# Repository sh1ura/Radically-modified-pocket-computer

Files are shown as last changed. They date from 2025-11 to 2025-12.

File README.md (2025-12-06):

# ポケコン Linux 化改造

appearances

1988年のポケットコンピュータ（ポケコン） SHARP PC-G801 を改造し、キーボードとディスプレイがついた Linux マシン化しました。

制作過程等は[こちら](https://shiura.com/dfab/sharp-mod/index.html)をごらんください。

### 動画

pockecom (https://youtu.be/T_GSy2BSDts)

## 概要

* Raspberry Pi Zero 2 W を内蔵
  - Linux (Raspberry Pi OS) が動作
  - C や Python など様々な言語でプログラミングが可能
  - WiFi でネットワークに接続でき、apt によるソフト追加・更新、pip による Python パッケージ追加など可能
* ESP32-S3 を内蔵
  - キーボード読み取り、ディスプレイ表示を担当
  - ターミナルは VT100 のサブセットで、emacs 等が使用可能
  - 漢字表示(UTF-8)簡易対応
  - ESP32 単体で起動すると、RPN 関数電卓として動作
* bluetoothキーボード機能を搭載(ESP32)
  - <a href="https://x.com/shiura/status/1997224685965336579">Linux の GUI 画面への文字入力（VNCやHDMIディスプレイの接続時）</a>に利用可能
  - 電卓モードでは<a href="https://x.com/shiura/status/1997232332638740924">計算結果の転送</a>も可能
* 裏面・側面に至るまで、オリジナルの外観をキープ
  - オリジナル同様、単３（ニッケル水素電池）４本で動作
 


### 回路・部品構成

design

 ## 提供物

 * 改造用の PCB （基板）のデータ
 * ESP32 上のコード（VT100サブセットターミナルとRPN関数電卓を統合したもの）
 * ディスプレイを固定するための治具の3Dモデル

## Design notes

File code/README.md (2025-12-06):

# ポケコン改造用 ESP32 コード

ESP32 で以下のことを行うコードです。非常に荒っぽい、汚いコードですのでご了承ください。

### ターミナルモード（Raspberry Pi 起動時）


* UART で Raspberry Pi と通信
  - Bluetoothキーボードとしても動作可能
* 全キーのスキャン（押下状態を取得）
  - 一部については文字コードを生成
  - shift (主に記号入力), caps (大文字入力), ctrl (BASICキー), ESC (カナキー)
* VT100サブセットの ANSI エスケープシーケンス処理
  - 必要最低限のコードのみ処理しています
    - 非対応のコードのため、emacs 等では時々表示がずれることがあります
  - 漢字表示(UTF-8)対応
    - 簡易処理のため、文字欠け等が生じることがあります
    - 表示文字数を減らさないため、漢字は上下に少し文字同士の重なりが生じます
  - カラー・反転等には対応していません
  - 42列7行表示
    - CLS ボタンを押すと `stty rows 7 cols 41; clear` のように画面サイズをセットするコマンドが自動入力されます
  - 履歴表示（上へのスクロール）
    - CONSTキー：上へスクロール　ANSキー : 下へスクロール
    - どれかのキーを押すと最下行へ復帰

### RPN 関数電卓モード（ESP32 単体動作時）


* スタック32段、表示5段のRPN関数電卓（三角関数、対数・指数関数など）
* 32段階のアンドゥ機能
* フルキーのアルファベットを用いた機能
  - A-F でスタックの深い位置にある値を取り出し可能
  - X-Z のメモリ機能（shift-X で保存、X で呼び出し）
* 計算結果の bluetooth 転送機能（キーボードデバイスとして動作）

### 共通

* **Bluetooth キーボード機能**
  - 2nd Fキーの押下で、いつでも、通常の動作状態と Bluetooth キーボード状態との間を行き来できます
  - ターミナルモード（Raspberry Pi 起動時）では、GUI画面を表示しているときのキー入力に利用できます（VNC利用時、HDMIディスプレイ接続時等）
  - RPN 関数電卓モード（ESP32 単体動作時）では、一般の bluetooth キーボードとしての動作に加え、電卓表示中も TAB キーを押すことで計算結果（スタックトップ）の数値をPCへ入力できます
* 10秒間操作しないと、ESP32 が間欠動作になります
  - ディスプレイが点いたままなので、表示文字数に応じて電力消費があります
* 30 秒間操作しないと、さらに画面が消灯します
  - RPN 関数電卓モードの場合、消費電力は 10mA 以下になります。
  - RPi モードのときは、待機中の消費電力は約 140mA になります。
* キーが押されると復帰します

### なお、Raspberry Pi Zero 2W 側はプログラミング不要です。

* [設定画面（GUI の「設定」、または CLI の raspi-config）で、シリアルポート有効、シリアルコンソール有効にセット](https://toki-blog.com/pi-serial/)してください。GPIO14/15 (TXD/RXD) からシリアル通信でログインできるようになります（起動時・シャットダウン時のメッセージも表示されます）。

## 依存ライブラリ

* [u8g2](https://github.com/olikraus/u8g2)
* [ESP32-BLE-Keyboard](https://github.com/JuniorPolegato/ESP32-BLE-Keyboard)
  - 必ず、BleKeyboard.h 冒頭の `#undef USE_NIMBLE` を `#define USE_NIMBLE` に変更してください

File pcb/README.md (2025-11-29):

# PCB データ

KiCad でデザインしたPCBのデータを公開します。

ki2

## 設計手順

1. キーマトリクスの配置を検討（9x10=19本のGPIOで読み取り）
2. 回路図作成
3. キーボードの導電ゴム接点をフットプリントエディタで作成
4. オリジナルの基板をスキャン
5. 画像に合わせてフットプリントを配置

ki1

## 作成結果(JLCPCB発注）

pcb1s

pcb2s

## 搭載・使用する部品

wirings
heights

### この PCB に搭載される部品

* ESP32-S3 搭載ボード
  - ESP32-S3 DevKitC と同じピン配置ですが、より短い形状のものです。[これ](https://www.amazon.co.jp/ESP32-S3-DevKit-N16R8-%E3%83%9C%E3%83%BC%E3%83%89%E9%96%8B%E7%99%BA%E3%83%9C%E3%83%BC%E3%83%89-%E6%A9%9F%E8%83%BD%E3%83%9E%E3%82%A4%E3%82%AF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)と同じものだと思います（私は AliExpress で購入）。
  - 片側（１列）だけを PCB に接続します。
* ピンソケット
  - 背が低いタイプが必要です。
  - [シングルピンソケット (低メス) 1×20 (20P)](https://akizukidenshi.com/catalog/g/g103138/)を使用しました。
  - ピンヘッダの取り付け方は[こちら](https://74th.hateblo.jp/entry/2022/12/19/124809)を参考にしてください。
* スライドスイッチ（電源スイッチ）
  - 型番 : SK13D07 と思われます。
  - １回路３接点（３ポジション）のものです。うち２ポジションを電源 ON として使用します。
  - 私は[これ](https://www.amazon.co.jp/dp/B0DKBTV5J2)を購入しました。
* ショットキーバリアダイオード
  - 型番 : SR560
  - Raspberry Pi と ESP32 の両方に電源を供給する場合と、ESP32 だけに供給する場合の２通りを実現するために用います。
  - ちょっと大きめですが、以前購入したストック（[これ](https://www.amazon.co.jp/dp/B07ZQM1Q4N)）を使用しました。
  - Raspberry Pi Zero を搭載しない場合は不要です
* L字ピンヘッダ、ピンソケットケーブル

### プロジェクト全体に必要な部品

ESP32-S3 だけを用いた端末に仕上げることも出来ます。その場合は Raspberry Pi Zero は不要です。

* 3.12インチ 256x64画素 OLED ディスプレイ（ドライバ IC : SSD1322）
  - 上のスペックで検索すると見つかる、[こちら](https://nuneno.cocolog-nifty.com/blog/2019/08/post-4b41cf.html)にあるものです。
  - 販売状態では SPI 通信の状態になっていないものが多いので、表面実装の抵抗器を移動させる必要があります。最近、最初から SPI 接続になっているもの（接続端子が２列でなく１列になったもの）も売られているようです。
  - ２列のピンヘッダが縦向きにはんだ付けされていて、ポケコンの筐体に入らないので、Ｌ字ピンヘッダに付け替えてあります。ピンヘッダの抜き方は[こちら](https://dreamerdream.hateblo.jp/entry/2023/08/07/170000)を参考にしてください。
  - 電源は、ESP32 の3.3V 出力（3V3）を接続しています。このカスタム PCB 上に 3V3 を取り出せるパッドがあります。
* Raspberry Pi Zero
  - このプロジェクトでは Raspberry Pi Zero 2 W を搭載していますが、初代の Zero 等でも問題ないはずです。 
  - 強力両面テープで貼り付けてあるだけです。
  - このカスタム PCB の power2 のパッドから電源供給します。
  - Ｌ字ピンヘッダで電源供給していましたが、配線抵抗による電圧降下があったため、別途太めの電線で電源を引きました。

## 配線

以下では、電源については記載されていません。

* ESP32 には、PCB 上で GND と 5V に配線されています。
* ディスプレイには、SPI のほか、電源端子へ ESP32 の 3V3 出力を配線しています。SPI のピン配置はソースコードで確認してください。
* Raspberry Pi Zero 2 W には、 PCB 上の power2 のパッドから 5V へ配線しています。もちろん GND の配線も必要です。
* UART は、それぞれの TX 出力を、相手側の RX へ接続してください。



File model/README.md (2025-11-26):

# ディスプレイ固定用治具

スクリーンショット 2025-11-26 23 38 52

* ディスプレイの４隅の穴を、M2 のタッピングネジ（とても短いもの）で止めてください。
  - [amazon 等で「M2ネジ 皿頭　タッピング」などと検索して出てくるセット](https://www.amazon.co.jp/dp/B08P1MNV9Z/)の中の、一番短いものを使っています。
* そして、この治具全体を PCB で抑えるようにして止めてください。

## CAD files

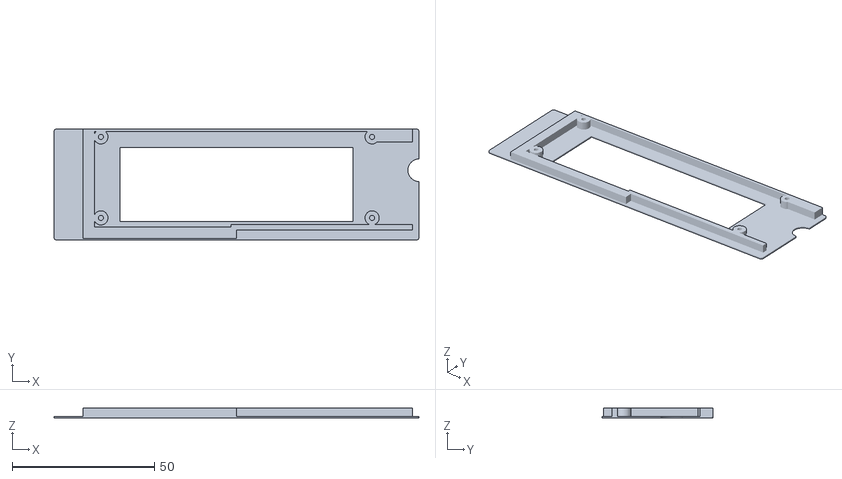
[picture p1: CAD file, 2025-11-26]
model/window.stl
128.4 x 39.2 x 3.60

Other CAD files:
model/window.blend

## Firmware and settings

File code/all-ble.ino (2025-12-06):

#include <Arduino.h>
#include <U8g2lib.h>
#include <SPI.h>
#include <BleKeyboard.h>


#define MODE_SENSE 36  // port to sense whether RPi-Zero is powered on or not
boolean rpiMode;       // RPi mode / ESP32 stand alone mode

BleKeyboard bleKeyboard;
boolean bleInit = false; // BLE is ready

//////////////////
// key definition
//////////////////

#define KEY_REPEAT 200
#define KEY_AVOID_CHATTERING 20

#define K_OUT_N 9  // number of key scan output port
#define K_IN_N 10  // number of key scan input port

int KeyPinOut[K_OUT_N] = { 10, 9, 46, 3, 8, 18, 17, 16, 15 };   // list of output ports
int KeyPinIn[K_IN_N] = { 14, 13, 12, 11, 7, 6, 5, 4, 38, 37 };  // list of input ports
#define SHIFT_ROW 0                                             // SHIFT key
#define SHIFT_CLM 0
#define CAPS_ROW 0  // CAPS key
#define CAPS_CLM 2
#define CTRL_ROW 1  // BASIC key
#define CTRL_CLM 0
#define HIS_UP_ROW 5  // CONST key
#define HIS_UP_CLM 2
#define HIS_DN_ROW 4  // ANS key
#define HIS_DN_CLM 2

// key matrix : row, clm
char keyMat[10][9] = {
  { 0, 0, 0, 0x1b, '\t', 0, ' ', 'B' + 0x80, 'A' + 0x80 },  // kana = ESC, cursor ESC[B, ESC[A
  { 0, 0, 'z', 'x', 'c', 'v', 'b', 'n', 'm' },
  { 0, 0, 'a', 's', 'd', 'f', 'g', 'h', 'j' },
  { 3, 'q', 'w', 'e', 'r', 't', 'y', 'u', 'i' },             // 3 : ctrl-C
  { 'D' + 0x80, 'C' + 0x80, 0, '0', '.', 0, '+', '\n', 0 },  // cursor ESC[D, ESC[C
  { ',', ';', 0, '1', '2', '3', '-', 0, 0 },
  { 'k', 'l', 0, '4', '5', '6', '*', 0, 0 },
  { 'o', 'p', 0x7F, '7', '8', '9', '/', 0, 0 },  // 8 : backspace
  { 0, 0, 0, 0, 0, 0, '(', ')', 0 },
  { 0, 0, 0, 0, 0, 0, 0, 0, 0 }
};

char keyMatCaps[10][9] = {
  { 0, 0, 0, 0, '\t', 0, ' ', 0, 0 },
  { 0, 0, 'Z', 'X', 'C', 'V', 'B', 'N', 'M' },
  { 0, 0, 'A', 'S', 'D', 'F', 'G', 'H', 'J' },
  { 0, 'Q', 'W', 'E', 'R', 'T', 'Y', 'U', 'I' },
  { 0, 0, 0, '0', '.', 0, '+', '\n', 0 },
  { '?', ':', 0, '1', '2', '3', '-', 0, 0 },
  { 'K', 'L', 0, '4', '5', '6', '*', 0, 0 },
  { 'O', 'P', 0, '7', '8', '9', '/', 0, 0 },
  { 0, 0, 0, 0, 0, 0, '(', ')', 0 },
  { 0, 0, 0, 0, 0, 0, 0, 0, 0 }
};

char keyMatShift[10][9] = {
  { 0, 0, 0, '_', '\t', 0, ' ', 0, 0 },
  { 0, 0, 0, 0, 0, 0, 0, 0, 0 },
  { 0, 0, '[', ']', '{', '}', '\\', '|', '~' },
  { 0, '!', '\"', '#', '$', '%', '&', '\'', '<' },
  { 0, 0, 0, '0', '.', 0, '+', '\n', 0 },
  { '?', ':', 0, '1', '2', '3', '-', 0, 0 },
  { '_', '=', 0, '4', '5', '6', '*', 0, 0 },
  { '>', '@', 0, '7', '8', '9', '/', 0, 0 },
  { 0, 0, 0, 0, 0, 0, '(', ')', 0 },
  { 0, 0, 0, 0, 0, 0, 0, 0, 0 }
};

struct KeyPos {
  int row;
  int clm;
  boolean caps;
  boolean shift;
  boolean ctrl;
};

//////////////////
// display definition
//////////////////

// Define your custom SPI pins
#define MY_SCK 1
#define MY_MISO 39
#define MY_MOSI 2
#define MY_SS 40  // Chip Select for other SPI devices, if any

U8G2_SSD1322_NHD_256X64_F_4W_HW_SPI u8g2(U8G2_R0, /* cs=*/40, /* dc=*/42, /* reset=*/41);  // Enable U8G2_16BIT in u8g2.h
#define DISP_WIDTH 256
#define DISP_HEIGHT 64
//#define FONT_TERM u8g2_font_mozart_nbp_tr
//#define FONT_TERM u8g2_font_6x10_mf
#define FONT_TERM u8g2_font_b12_t_japanese3  // with kanji
#define FONT_CALC u8g2_font_6x13_mf
#define FONT_TERM_HEIGHT 9
#define FONT_CALC_HEIGHT 12
#define FONT_WIDTH 6
int fontHeight = FONT_TERM_HEIGHT;

#define TEXT_WIDTH (DISP_WIDTH / FONT_WIDTH)
#define TEXT_HEIGHT (DISP_HEIGHT / fontHeight)

#define HISTORY_LINES 100  // rows of history area

//////////////////
// keyboard funcs
//////////////////

struct KeyPos keyCheck(void) {
  struct KeyPos key = { -1, -1, false, false, false };

  for (int o = 0; o < K_OUT_N; o++) {
    pinMode(KeyPinOut[o], OUTPUT);
    digitalWrite(KeyPinOut[o], LOW);
    for (int i = 0; i < K_IN_N; i++) {
      if (digitalRead(KeyPinIn[i]) == LOW) {
        if (i == CAPS_ROW && o == CAPS_CLM) {
          key.caps = true;
        } else if (i == SHIFT_ROW && o == SHIFT_CLM) {
          key.shift = true;
        } else if (i == CTRL_ROW && o == CTRL_CLM) {
          key.ctrl = true;
        } else {
          key.row = i;
          key.clm = o;
        }
      }
    }
    pinMode(KeyPinOut[o], INPUT);
  }
  return key;
}

char keyChar(struct KeyPos key) {
  static unsigned long time;
  static char c, c2;

  if (key.row < 0) {  // key release
    time = millis() - KEY_REPEAT + KEY_AVOID_CHATTERING;
    return 0;
  }
  if (key.caps)
    c = keyMatCaps[key.row][key.clm];
  else if (key.shift)
    c = keyMatShift[key.row][key.clm];
  else if (key.ctrl)
    c = keyMat[key.row][key.clm] & 0x1f;
  else
    c = keyMat[key.row][key.clm];

  if (c == c2 && time + KEY_REPEAT > millis()) {  // avoid chattering / repeat
    return 0;
  }
  time = millis();
  c2 = c;

  return c;
}

void waitRelease(void) {
  struct KeyPos keyRaw;
  do {
    keyRaw = keyCheck();
  } while (keyRaw.row >= 0);
}

//////////////////
// display funcs
//////////////////

char historyBuf[HISTORY_LINES][TEXT_WIDTH + 1];
char (*textBuf)[TEXT_WIDTH + 1] = &(historyBuf[HISTORY_LINES - TEXT_HEIGHT]);
int cursorX, cursorY;
boolean cursorOff;
int dispLine = HISTORY_LINES - TEXT_HEIGHT;
#define MIN(a, b) ((a) < (b) ? (a) : (b))
#define MAX(a, b) ((a) > (b) ? (a) : (b))

void resetDisplaySetting(void) {
  textBuf = &(historyBuf[HISTORY_LINES - TEXT_HEIGHT]);
  dispLine = HISTORY_LINES - TEXT_HEIGHT;
  cursorX = 0;
  cursorY = 0;
  cursorOff = false;
}

void turnOffDisplay(void) {
  u8g2.clearBuffer();
  u8g2.sendBuffer();  // transfer internal memory to the display
}

void refleshDisplay(void) {
  char c2[2] = " ";

  char(*showBuf)[TEXT_WIDTH + 1] = &(historyBuf[dispLine]);
  u8g2.clearBuffer();
  for (int j = 0; j < TEXT_HEIGHT; j++) {
    showBuf[j][TEXT_WIDTH] = '\0';
    // u8g2.drawStr(0, (j + 1) * fontHeight - 1, showBuf[j]);
    u8g2.setCursor(0, (j + 1) * fontHeight - 1);
    u8g2.print(showBuf[j]);  // ready for UTF8
  }

  if (!cursorOff && dispLine == HISTORY_LINES - TEXT_HEIGHT) {  // show cursor
    u8g2.setDrawColor(2);                                       // xor
    u8g2.drawBox(cursorX * FONT_WIDTH, cursorY * fontHeight,
                 FONT_WIDTH, fontHeight);
    u8g2.setDrawColor(1);
  }

  u8g2.sendBuffer();  // transfer internal memory to the display
}

void showString(const char *s) {
  for (int i = 0; s[i] != '\0'; i++) {
    showChar(s[i]);
  }
}

void scrollUp(void) {  // scroll up including history area
  for (int i = 0; i < HISTORY_LINES - 1; i++) {
    for (int j = 0; j < TEXT_WIDTH; j++) {
      historyBuf[i][j] = historyBuf[i + 1][j];
    }
  }
  for (int j = 0; j < TEXT_WIDTH; j++) {
    historyBuf[HISTORY_LINES - 1][j] = ' ';
  }
}

void scrollDown(void) {  // scroll down of visible area only
  for (int i = TEXT_HEIGHT - 1; i > 0; i--) {
    for (int j = 0; j < TEXT_WIDTH; j++) {
      textBuf[i - 1][j] = textBuf[i][j];
    }
  }
  for (int j = 0; j < TEXT_WIDTH; j++) {
    textBuf[0][j] = ' ';
  }
}

void eraseLine(int mode) {  // 0 : erase right, 1 : erase left, 2 : erase whole line
  int start = 0;
  int end = TEXT_WIDTH;

  switch (mode) {
    case 0:
      start = cursorX;
      break;
    case 1:
      end = cursorX;
      break;
  }
  for (int j = start; j < end; j++) {
    textBuf[cursorY][j] = ' ';
  }
}

void eraceLines(int mode) {
  int start = 0;
  int end = TEXT_HEIGHT;

  switch (mode) {
    case 0:
      start = cursorY + 1;
      break;
    case 1:
      end = cursorY;
      break;
  }
  for (int i = start; i < end; i++) {
    for (int j = 0; j < TEXT_WIDTH; j++) {
      textBuf[i][j] = ' ';
    }
  }
  eraseLine(mode);
}

void escProcess(String str) {  // process escape sequence
  int end = str.charAt(str.length() - 1);
  str = str.substring(0, str.length() - 1);
  if (str.charAt(0) == '[') {  // CSI (Control Sequence Introducer)
    str = str.substring(1);
    int num = str.toInt();
    if (str.length() == 0)
      num = 1;
    switch (end) {
      case 'A':
        cursorY = MAX(cursorY - num, 0);
        break;
      case 'B':
        cursorY = MIN(cursorY + num, TEXT_HEIGHT - 1);
        break;
      case 'C':
        cursorX = MIN(cursorX + num, TEXT_WIDTH - 1);
        break;
      case 'D':
        cursorX = MAX(cursorX - num, 0);
        break;
      case 'E':
        cursorX = 0;
        cursorY = MIN(cursorY + num, TEXT_HEIGHT - 1);
        break;
      case 'F':
        cursorX = 0;
        cursorY = MAX(cursorY - num, 0);
        break;
      case 'G':
        cursorX = MAX(MIN(num - 1, TEXT_WIDTH - 1), 0);
        break;
      case 'J':
        eraceLines(str.toInt());
        break;
      case 'K':
        eraseLine(str.toInt());
        break;
      case 'H':
      case 'f':
        if (0 <= str.indexOf(';')) {
          cursorY = str.toInt() - 1;
          cursorX = str.substring(str.indexOf(';') + 1).toInt() - 1;
          cursorX = MAX(MIN(cursorX, TEXT_WIDTH - 1), 0);
          cursorY = MAX(MIN(cursorY, TEXT_HEIGHT - 1), 0);
        } else {
          cursorX = 0;
          cursorY = 0;
        }
        break;
      case 'S':
        for (int n = 0; n < num; n++) {
          scrollUp();
        }
        break;
      case 'T':
        for (int n = 0; n < num; n++) {
          scrollDown();
        }
        break;
      case '@':  // insert space (scroll right)
        for (int j = TEXT_WIDTH - num - 1; j >= cursorX; j--) {
          textBuf[cursorY][j + num] = textBuf[cursorY][j];
        }
        for (int j = cursorX; j < cursorX + num; j++) {
          if (j >= TEXT_WIDTH)
            break;
          textBuf[cursorY][j] = ' ';
        }
        break;
      case 'P':  // delete charactor (scroll left)
        for (int j = cursorX; j < TEXT_WIDTH; j++) {
          textBuf[cursorY][j] = (j + num < TEXT_WIDTH) ? textBuf[cursorY][j + num] : ' ';
        }
        break;
      case 'h':
        if (str == "?25")
          cursorOff = false;
        break;
      case 'l':
        if (str == "?25")
          cursorOff = true;
        break;
    }
  }
}

#define PROCESS_ESC 1
#define DEBUG_ESC 0

void showChar(char c) {
  static boolean esc;
  static String escStr;

  if (!c)
    return;

#if DEBUG_ESC
  char c2[2] = " ";
  c2[0] = c;
  Serial.print(c2);
#endif

#if PROCESS_ESC
  if (esc) {
    char c2[2] = " ";
    c2[0] = c;
    escStr += c2;
    if (c != '[' && (0x40 <= c && c <= 0x7f)) {  // escape sequence end
      esc = false;
      escProcess(escStr);
    }
    return;
  }
  if (c == 0x1b) {  // escape sequence start
    esc = true;
    escStr = "";
    return;
  }

  if (0x0A <= c && c <= 0x0C) {  // LF / VT / FF
    cursorX = 0;
    cursorY++;
  } else if (c == 0x0D) {
    cursorX = 0;
  } else if (c == 0x08 || c == 0x7F) {  // backspace
    cursorX = MAX(cursorX - 1, 0);
  } else if (c == 0x09) {  // tab, HT
    cursorX = cursorX + 8;
    cursorX -= cursorX % 8;
  } else {
#else  // show special characters
  {
    if (c < 0x20)
      c += 0xc0;
#endif
    if (c >= 0x20) {
      textBuf[cursorY][cursorX] = c;
      cursorX++;
    }
  }
  if (cursorX >= TEXT_WIDTH) {
    cursorX = 0;
    cursorY++;
  }
  if (cursorY >= TEXT_HEIGHT) {
    scrollUp();
    cursorY--;
  }
}

//////////////////
// RPi mode VT100 console main loop
//////////////////

void loopRpi(struct KeyPos key) {
  char c;
  char c2[2] = " ";
  boolean dispFlag = false;
  static unsigned long lastExec = millis();  // sleep timer
  static boolean dispOff = false;

  while (Serial2.available()) {
    c = Serial2.read();
    showChar(c);
    dispFlag = true;
  }
  if (dispFlag) {
    refleshDisplay();
    dispOff = false;
    lastExec = millis();
  }

  if (key.row == HIS_UP_ROW && key.clm == HIS_UP_CLM) {
    dispLine = MAX(dispLine - 1, 0);
    refleshDisplay();
    delay(50);
    return;
  } else if (key.row == HIS_DN_ROW && key.clm == HIS_DN_CLM) {
    dispLine = MIN(dispLine + 1, HISTORY_LINES - TEXT_HEIGHT);
    refleshDisplay();
    delay(50);
    return;
  } else if (key.row == 9 && key.clm == 8) {  // CLS key
    char c3[100];
    sprintf(c3, "stty rows %d cols %d; clear", TEXT_HEIGHT, TEXT_WIDTH - 1);
    Serial2.print(c3);
    waitRelease();
  }
  c = keyChar(key);
  if (c == 0) {
    if (lastExec + 10000 < millis()) {    // no operation for 10 sec
      if (lastExec + 30000 < millis()) {  // for 30sec, turn off the display
        if (!dispOff) {
          turnOffDisplay();
          dispOff = true;
        }
      }
      esp_sleep_enable_timer_wakeup(300000);  // 0.3sec
      esp_sleep_enable_uart_wakeup(UART_NUM_2);
      esp_light_sleep_start();
    }
    return;
  }
  if (dispOff) {  // display turn on by hitting any key
    refleshDisplay();
    dispOff = false;
  }
  dispLine = HISTORY_LINES - TEXT_HEIGHT;  // reset display area
  if (c & 0x80) {                          // escape sequence
    char c3[4] = { 0x1b, '[', ' ', 0 };
    c3[2] = c & 0x7f;
    Serial2.print(c3);
  } else {
    c2[0] = c;
    Serial2.print(c2);
  }
  lastExec = millis();
}

//////////////////
// ESP32 mode calculator
//////////////////

#define MAX_DIGIT 19
#define NUM_WIDTH 17

#define STACK_DEPTH 32
double stack[STACK_DEPTH];

void push(double v) {
  for (int i = STACK_DEPTH - 1; i > 0; i--) {
    stack[i] = stack[i - 1];
  }
  stack[0] = v;
}

double pop() {
  double v;
  v = stack[0];
  for (int i = 0; i < STACK_DEPTH - 1; i++) {
    stack[i] = stack[i + 1];
  }
  stack[STACK_DEPTH - 1] = 0;
  return v;
}

#define UNDO_DEPTH 32
int undoTop = 0;
double undoBuf[UNDO_DEPTH][STACK_DEPTH];

void backup(void) {
  if (undoTop >= UNDO_DEPTH) {
    for (int i = 0; i < UNDO_DEPTH - 1; i++) {
      for (int j = 0; j < STACK_DEPTH; j++) {
        undoBuf[i][j] = undoBuf[i + 1][j];
      }
    }
    undoTop--;
  }
  for (int j = 0; j < STACK_DEPTH; j++) {
    undoBuf[undoTop][j] = stack[j];
  }
  undoTop++;
}

void restore(void) {
  if (undoTop == 0)  // no undo data
    return;
  undoTop--;
  for (int j = 0; j < STACK_DEPTH; j++) {
    stack[j] = undoBuf[undoTop][j];
  }
}

void messageBox(String str) {
  int width = str.length() * FONT_WIDTH;
  width = width / 2 + 10;

  u8g2.setDrawColor(1);  // xor
  u8g2.drawBox(DISP_WIDTH / 2 - width - 1, DISP_HEIGHT / 2 - fontHeight - 1,
               width * 2 + 2, fontHeight * 2 + 2);
  u8g2.setDrawColor(0);  // xor
  u8g2.drawBox(DISP_WIDTH / 2 - width, DISP_HEIGHT / 2 - fontHeight,
               width * 2, fontHeight * 2);

  u8g2.setCursor(DISP_WIDTH / 2 - width + 10, DISP_HEIGHT / 2 + fontHeight / 2 - 1);
  u8g2.setDrawColor(1);
  u8g2.print(str);
  u8g2.sendBuffer();  // transfer internal memory to the display
}

void dispClear(void) {
  for (int i = 0; i < TEXT_HEIGHT; i++) {
    for (int j = 0; j < TEXT_WIDTH; j++) {
      textBuf[i][j] = ' ';
    }
  }
}

#define VARIABLE_NUM 3
#define VARIABLE_LETTER 'X'
double memory[VARIABLE_NUM];  // variable memory X, Y, Z

boolean degree = false;  // radian / degree
String enteringStr = "";

void update_display(void) {
  int entlen = enteringStr.length();

  resetDisplaySetting();
  dispClear();
  cursorX = MAX_DIGIT + 3;
  cursorY = 0;
  showString(degree ? "degree" : "radian");

  for (int i = 0; i < VARIABLE_NUM; i++) {  // show content of variable numbers
    if (memory[i] != 0) {
      String s = " ";
      s[0] = VARIABLE_LETTER + i;
      s = s + fp64_to_string_wrap(memory[i]);
      cursorX = MAX_DIGIT + 3;
      cursorY = i + 1;
      showString(s.c_str());
    }
  }
  for (int i = 0; i < TEXT_HEIGHT; i++) {
    String s = " ";
    s[0] = 'F' - i;
    if (s[0] < 'A')
      s[0] = ' ';
    s = s + fp64_to_string_wrap(stack[i]);
    cursorX = 0;
    cursorY = TEXT_HEIGHT - 1 - i;
    showString(s.c_str());
  }
  String dispEntStr;
  if (entlen > NUM_WIDTH - 2) {
    dispEntStr = ".." + enteringStr.substring(entlen - (NUM_WIDTH - 2));
  } else {
    dispEntStr = ">" + enteringStr;
    dispEntStr = dispEntStr.substring(0, NUM_WIDTH);
  }
  cursorX = MAX_DIGIT + 3;
  cursorY = TEXT_HEIGHT - 1;
  showString(dispEntStr.c_str());
  refleshDisplay();
}

String fp64_to_string_wrap(double n) {
  char str[30];
  String s;

  sprintf(str, "%15.13g", n);

  s = str;
  while (s.length() < MAX_DIGIT) {
    s = " " + s;  // align right
  }
  return s;
}

double toRad(double x) {
  if (degree) {
    return x * M_PI / 180.0;
  } else return x;
}

double fromRad(double x) {
  if (degree) {
    return x * 180.0 / M_PI;
  } else return x;
}

void enter(void) {
  if (enteringStr.length()) {
    backup();
    push(atof((char *)enteringStr.c_str()));
    enteringStr = "";
  }
}
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
void loop() {
  struct KeyPos keyRaw;
  boolean bleMode;

  keyRaw = keyCheck();
  if (checkBleMode(keyRaw)) {
    bleLoop(keyRaw);
  } else if (rpiMode) {
    loopRpi(keyRaw);
  } else {
    loopESP32(keyRaw);
  }
}

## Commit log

2025-11-26 Create README.md for ポケコン Linux 化改造 project
    Added a README file detailing the modification of the SHARP PC-G801 into a Linux machine.
2025-11-26 Update README with video and provided materials
    Added video link and details about provided materials.
2025-11-26 Create README.md for PCB design documentation
    Added a README file with PCB design information and steps.
2025-11-26 PCB for modifying SHARP PC-G801
2025-11-26 Update README with component specifications
    Added details about components used in the PCB.
2025-11-26 Add README for display fixture setup
    Added instructions for securing the display fixture using M2 screws.
2025-11-26 Fix formatting for diode part number in README
    Corrected formatting for the part number of the Schottky barrier diode.
2025-11-28 independent fonts for ESP32 and RPi mode
    for ESP32, larger font (5 rows)
    for RPi, smaller font (7 rows)
2025-11-29 send stty command by pressing CLS button
    send "stty rows 7 cols 41; clear" when pressing CLS button for quick configuration of console size.
2025-11-29 Clarify L-shaped pin header and Raspberry Pi usage
    Updated the README to clarify the use of L-shaped pin headers and Raspberry Pi models.
2025-11-30 add power saving feature
    after 30 seconds without operation, display is turned off and ESP32 sleeps.
    During sleep (display off)
    ESP32 mode (RPN calc) : 0mA
    RPi mode (Linux) : 140mA
2025-12-06 Add Bluetooth keyboard functionality for ESP32
    Added Bluetooth keyboard functionality for ESP32, enabling text input to Linux GUI and result transfer in calculator mode.
